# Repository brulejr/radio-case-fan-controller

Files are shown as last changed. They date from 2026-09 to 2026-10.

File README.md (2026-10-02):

# Radio Case Fan Controller

ESP32 + ESPHome temperature-controlled fan module for cooling enclosed radio
equipment cases (initial target: the ICOM IC-2730A compact organizer, reusable
for other go-box modules). Supports one Noctua 5V PWM fan (outbound only,
passive intake) or two (matched outbound + inbound), switchable in software.

## Status

**Working prototype, in production use.** Built on a protoboard carrier and
running in the radio case: temperature-driven fan control, dual-fan operation
and RPM monitoring are all verified on hardware.

The custom carrier PCB (rev A) is drawn and checked — see
[`hardware/pcb/`](hardware/pcb/) — and is ready to order.
The enclosure follows. Breadboard was development-lab only and is behind us.

## Hardware on hand

- ESP32-C6-WROOM-1 dev board (RISC-V, 2×15 headers, dual USB-C)
- HiLetgo DS18B20 waterproof temperature probe (1-Wire, stainless steel, ~380 mm cable)
- Noctua NF-A4x20 5V PWM fan(s)
- 12V → 5V buck converter with a **USB-C output** (any module ≥1A)

## Schematic

[`hardware/schematic.svg`](hardware/schematic.svg) — full electrical diagram.
[`docs/wiring.md`](docs/wiring.md) has the net-by-net connection table, the
connector pinouts, the BOM, and the order to bring the board up in.

Schematic

## Pinout (ESP32-C6-WROOM-1 dev board)

| Signal | GPIO | Side | Notes |
| --- | --- | --- | --- |
| DS18B20 data (1-Wire) | GPIO6  | Left | 4.7kΩ pull-up to 3.3V between data and VCC |
| Fan 1 (outbound) PWM  | GPIO20 | Right  | Hardware LEDC output, 25kHz per Noctua PWM spec  |
| Fan 1 tach | GPIO21 | Right  | Open-collector; 10kΩ pull-up to **3.3V**, not 5V |
| Fan 2 (inbound) PWM | GPIO18 | Right  | Hardware LEDC output, 25kHz |
| Fan 2 tach | GPIO19 | Right  | Open-collector; 10kΩ pull-up to **3.3V**, not 5V |

Pins chosen to avoid the C6 strapping pins (4, 5, 8, 9, 15 — 8 also drives the
onboard RGB LED, 9 is the BOOT button, 15 has no internal pull), the USB
Serial/JTAG pair (12, 13), and the UART0 pins wired to the USB bridge (16, 17).
GPIO14 is not broken out, and GPIO24–30 are consumed by the SPI flash bus.

The four fan signals sit as a contiguous block on the right header while the
1-Wire probe is on the left, putting it on the physically opposite side of the
board from the 25kHz PWM edges. Spare after this: GPIO0, 1, 2, 3, 7, 10, 11,
22, 23.

## Power wiring

- Radio supply (12V nominal, wide tolerance) → buck converter input, direct.
  No protection components by design — the box is fed from a battery or bench
  supply, which handle surge and reverse polarity at the source
- The buck's only output is **USB-C**, so 5V reaches the board through a USB-C
  cable into one of the dev board's two ports
- Both fans take 5V and GND from the dev board's header pins — so **fan power
  depends on the dev board**. See the power topology section of
  [`docs/wiring.md`](docs/wiring.md) for what that implies
- **One power source at a time**: the buck and both USB-C ports share a net.
  Don't leave the buck connected while a computer is plugged in
- No bulk or decoupling caps on the 5V rail; 4-pin PWM fans don't chop their
  supply current, and the dev board has its own input decoupling

## Fan PWM/tach notes

- Noctua 4-pin fans expect ~25kHz on the PWM control line; the ESP32-C6's
  hardware `LEDC` peripheral hits this natively at ~11-bit resolution (this is
  why an ESP32-class part over an ESP8266 — ESP8266's software PWM can't
  cleanly reach 25kHz and tends to produce audible whine)
- Tach line is open-collector: it only pulls low, never drives high, so a
  simple pull-up to 3.3V is safe — no level shifting needed
- Fans report 2 tach pulses per revolution; the ESPHome config's
  `pulse_counter` filter accounts for this
- **No PWM signal means full speed**, not stopped — the fan pulls its control
  input high internally. Expect a spin-up if you unplug a PWM line while the
  fan is powered
- Each fan draws 0.1A / 0.5W at full speed (Noctua spec)

## Software

`icom2370a-fan-controller.yaml` — ESPHome config. Key behavior:

- DS18B20 reading drives a linear PWM ramp between a configurable min/max
  temperature (exposed as tunable `number` entities, not hardcoded)
- "Dual Fan Mode" switch: on = both fans run the same curve; off = only
  Fan 1 (outbound) runs, Fan 2 output held at 0% for passive-intake mode
- Fallback WiFi AP + local API so the module stays controllable if the
  field WiFi network isn't up
- Local web UI at `http://<device-ip>/` for the sensors, fan-curve numbers and
  Dual Fan Mode switch, with its assets embedded in flash so it works with no
  internet. Needs `web_server_username` / `web_server_password` in `secrets.yaml`

### First flash

1. Copy `secrets.yaml.example` to `secrets.yaml` and fill in your values
2. Flash. The boot log lists the 1-Wire devices found on GPIO6; confirm the
   probe enumerates. No address needs configuring — see the note in the YAML
3. Confirm fan curve thresholds via Home Assistant or the ESPHome web UI
   before buttoning up the enclosure

## Repo layout

```
/esphome/icom2370a-fan-controller.yaml    # ESPHome config
/esphome/secrets.yaml.example
/hardware/schematic.svg                    # schematic / wiring diagram
/hardware/esp32-photo.jpg                  # dev board + protoboard carrier, for the header map
/hardware/pcb/                             # KiCad 8 carrier PCB, rev A
/docs/wiring.md                            # net list, connection table, BOM, bring-up order
README.md
.gitignore
```

Still to come under `/hardware/`: the OpenSCAD enclosure.

## Problem solving

Lessons from first bring-up on real hardware. [`docs/wiring.md`](docs/wiring.md)
carries the electrical detail.

### Start with the `[D][fan]` log line

It prints every 5s and shows the live setpoints alongside the computed duty:

```
[D][fan:197]: t=32.88 lo=25.0 hi=45.0 floor=0.30 -> duty=0.674 dual=1
```

The three setpoints are `restore_value: true`, so whatever you last set from the
web UI or Home Assistant **outranks `initial_value` in the YAML** and survives
both reboots and OTA updates. Trust this line, not the config file.

### Symptom table

| Symptom | Likely cause |
| --- | --- |
| Fan runs constantly, RPM flat `0.00`, no response to duty changes | PWM and tach swapped at the fan connector. Verify by **wire colour** — blue is PWM, green is tach — because pin numbering is exactly what's unreliable when this happens |
| Fan runs at full speed | No PWM signal reaching it. An open control line is held high by the fan's internal pull-up, which reads as 100% duty |
| Fan seems to idle quietly | It may in fact be at 100%. An NF-A4x20 is only ~18 dB(A) flat out, so full speed and idling sound alike without a reference |
| Fan turns at 0% duty | Something is wrong upstream — this fan **does** stop at 0%, verified on the bench |
| RPM reads `0.00` while the fan spins | Tach pull-up on the wrong rail, or the tach line open. A spinning fan's tach reads ~1.6V on a DC meter; a flat rail voltage means no pulses |
| Low hum on nearby 2 m / 70 cm radios while the fans run | Check both tach pull-up joints (R2/R3, 10 kΩ) first — a disconnected one was found during the investigation. RC filters, ferrites and the probe made no difference. Not yet fully resolved |
| RPM reads absurdly high (~234,000) | The `multiply` filter is wrong. `pulse_counter` reports pulses/min, so RPM = pulses/min ÷ 2 |

### Techniques worth remembering

**Raw versus published values.** `[D][pulse_counter]` prints the raw
`pulses/min`, untouched by filters. Comparing it against the published RPM
separates a sensor problem from a scaling problem.

**Measure at both ends of a wire.** Continuity from a GPIO to a header pin says
nothing about whether the fan's own conductor is landed there. Assuming it did
cost several rounds of diagnosis.

**Slow RPM feedback?** The pulse counters run at `update_interval: 60s`. Drop
them to `10s` temporarily while chasing a tach problem, then put them back.

**Changing setpoints without Home Assistant.** The device serves a local page at
`http://<device-ip>/` with the fan-curve numbers and the Dual Fan Mode switch.
Assets are embedded in flash, so it works with no internet.

**RF interference tests: no temperature means no PWM.** The control loop
returns early while the temperature is invalid, so with the probe unplugged, or
with `update_interval: never`, the PWM lines never switch and the fans get no
commanded duty. Any test that removes the probe therefore also changes the fans.
To separate them, leave the probe in and move **Fan Curve Min Temp** above or
below the case temperature — and **confirm from the `[D][fan]` duty and the RPM
readings which fans are actually running** before judging a result.

**Reference figures.** At ~67% duty expect roughly 4,050 RPM (Fan 1,
outbound) and 3,900 RPM (Fan 2, inbound) — useful for judging whether a reading
is plausible. (Recorded before the fan pin assignments were corrected, when the
entity names were swapped; the figures are attributed to the physical fans.)

## TODO

- [x] Design a custom PCB for the carrier board, using the protoboard build as
      the reference (rev A, [`hardware/pcb/`](hardware/pcb/))
- [x] Confirm the dev board header row spacing (25.4 mm)
- [ ] Order the rev A boards
- [ ] Design enclosure (OpenSCAD) once the PCB is finalized
- [ ] Consider stall detection (tach == 0 while PWM > 0) as a fault alert

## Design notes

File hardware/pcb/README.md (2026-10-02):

# Carrier PCB — rev A

KiCad 8 project for the custom carrier board that replaces the protoboard. The
ESP32-C6 dev board from the prototype plugs in unchanged. The buck converter
moves onto the board, so there's no USB-C cable between them. Every passive is
**through-hole**, for hand assembly.

Board, top view

| File | What |
| --- | --- |
| `fan-controller-carrier.kicad_sch` | schematic |
| `fan-controller-carrier.kicad_pcb` | layout, 2-layer, 1.6 mm |
| `carrier-top.svg` | preview render (copper + silk) |
| `fit-template.pdf` | 1:1 printable outline for space checking  |

Only stock KiCad 8 libraries are used. Nothing needs installing beyond KiCad.
ERC, DRC and schematic parity are all clean.

## Dev board header spacing

The socket rows J5/J6 are **25.4 mm (10 × 0.1") apart, centre to centre**,
confirmed against the dev boards on hand (2026-10-01). Boards of this type come
in 0.1" steps (22.86 / 25.4 / 27.94 mm), so a different dev board needs
checking before reuse. To change it, move J6 and re-route the filter block
between the rows.

## Board

- **90 × 54 mm**, sized for a **Hammond 1590B** die-cast box (inside 107 ×
  55.4 mm at the floor, 27 mm deep). The board sits between the lid-screw
  bosses with about 0.7 mm spare on each long side.
- 4 × M3 holes, 3.5 mm in from each corner. They are **not plated**, and there
  is a 3.6 mm copper keepout around each one. The screw heads and standoffs
  never touch GND, so board ground stays isolated from the enclosure.
- The bottom layer is almost entirely GND. It carries only the 5 V feed to the
  fans and two short tach links in the filter block.

### Height stack

| Item | mm, approx. |
| --- | --- |
| standoff | 5 |
| carrier PCB | 1.6 |
| female socket | 8.5 |
| dev board + USB-C / module | 5 |
| **top of dev board above enclosure floor** | **~20** |

U1, the electrolytics (~10–11 mm) and the fan plugs (~12 mm above the PCB) are
lower than that, which leaves about 7 mm under the 1590B's lid.

The filter block and R1 sit **under the dev board**, inside the 8.5 mm socket
gap. Lay the resistors flat and seat the disc capacitors low, with no more
than ~6 mm of body and leads above the board.

## Layout

```
 x=0 (left end panel)                                        x=90 (right end panel)
 ┌──────────────────────────────────────────────────────────────────┐
 │ H1                                                           H2  │
 │ J4 probe (XH, top) R6 C7 ─ top edge ─▶ GPIO6   ┌── dev board ──┐│
 │                                                │ J5 RST ... 5V ││ ANTENNA
 │ J1 12V  U1 R-78E      12V/USB warning   ◀USB  │  filter block ││ keepout
 │         C1 C2                                  │ J6 GND ... 5V ││
 │ J3 FAN2  J2 FAN1  C9 C8  5V FANS ONLY ◀─ lanes ─└───────────────┘│
 │ H3                                                           H4  │
 └──────────────────────────────────────────────────────────────────┘
```

- **Left end:** J1 (12 V) has its wire entry facing the left edge. J4 (probe)
  takes its plug from above. Both fan headers are in the bottom-left corner,
  also plugged from above, so the board can lie flat facing up.
- **Dev board:** the USB end points into the board and the antenna end
  overhangs the right edge, with a copper keepout under the antenna on both
  layers.
- **Filter block,** between the socket rows, in four rows starting nearest J6:

  | Row | Parts | Channel |
  | --- | ----- | ------- |
  | A | R4 + C3 | PWM1, GPIO20 |
  | B | R5 + C4 | PWM2, GPIO18 |
  | C | C5 + R2 | TACH1, GPIO21 |
  | D | C6 + R3 | TACH2, GPIO19 |

  Each filtered PWM line passes between two adjacent socket pins (0.3 mm track,
  0.27 mm clearance) to reach its lane. The tach parts connect on the bottom
  layer, so the tach and PWM lines never cross.
- **Fan lanes:** four non-crossing traces run to the headers, 1.5 mm apart:
  - GPIO18/19 → J3 (Fan 2, inbound, left header)
  - GPIO20/21 → J2 (Fan 1, outbound, right header)
- **1-Wire:** runs along the top edge, on the opposite side of the board from
  the fan lanes.

## Filtering

Rationale for each filter, from the prototype's RF interference investigation:

| Parts | Where | Why |
| ----- | ----- | --- |
| **C5/C6** 1 nF, with R2/R3 10 kΩ | tach lines, at the GPIO | The one prototype change that clearly reduced the hum was restoring a lost 10 kΩ tach pull-up. The likely mechanism is PWM edges coupling onto a weakly held tach line. The cap shunts that coupling; the 10 µs time constant is far shorter than the ≥ 6 ms between tach pulses. |
| **R4/C3, R5/C4** 220 Ω + 10 nF | PWM lines, at the GPIO | Insurance. It made no difference to the hum on the prototype, but it's proven harmless (fan control works through it) and it softens edges that run beside the tach wire in each fan cable. |
| **R6** 0 Ω, **C7** not fitted | 1-Wire, at J4 | Spare footprints: a ferrite and an RC on this line made no difference on the prototype. If C7 is ever fitted, keep it **≤ 470 pF**, or the 1-Wire bus stops working. |
| **C8/C9** 10 µF + 100 nF | fan 5 V, beside J2 | Standard decoupling, shared by both headers. |

The interference wasn't fully resolved on the prototype. See **RF interference**
below.

## Connectors

| Ref | Part | Mates with |
| --- | ---- | --- |
| J1 | 2-pos screw terminal, 5.08 mm (Phoenix MKDS 1,5/2-5,08) | 12 V leads, or a Powerpole pigtail |
| J2, J3 | 4-pin PC fan header, Molex 47053-1000 (DigiKey WM4330-ND) | the fan's own connector, via a 4-pin PWM extension such as the Noctua NA-EC1 (30 cm; chainable) |
| J4 | JST XH 3-pin, top entry (**B3B-XH-A**) — the plug goes straight down | XHP-3 housing + SXH crimps on the probe leads, or a pre-crimped XH pigtail soldered and heat-shrunk to them |

- **XH pitch is 2.50 mm,** not 2.54 mm, even though it's often sold as 2.54.
- **Meter the probe's wires before crimping.** Some batches use white for data.
- **The XH latch is friction only.** In the go-box, add a dab of RTV silicone
  or a cable tie.
- **Keep the fan extensions keyed and 4-wire.** A PWM/tach swap has bitten this
  build before, and some cheap extensions are 3-wire and drop PWM.

## Changes from the protoboard build

| | Protoboard | PCB rev A |
| -- | -- | -- |
| Buck | USB-C-output module, off-board, cable into dev board | **R-78E5.0-1.0** SIP-3 switching regulator on board (U1), with C1 10 µF / C2 22 µF |
| 5 V to dev board | USB-C cable | U1 drives the socket's two **5V pins** (= dev board VBUS) |
| Fan 5 V | from the dev board's 5V pins | straight from U1. Fans no longer depend on the dev board |
| Fans | screw terminals | keyed 4-pin headers + extension cables |
| Probe | screw terminal | JST XH |
| Filtering | none | see **Filtering** above |
| Everything else | — | same nets, GPIOs and pull-up values |

The "one power source at a time" rule still applies, and it is printed on the
silkscreen. With 12 V on the board, the dev board's USB VBUS is live. **Unplug
12 V before plugging in a USB cable.** Flash over OTA once the board is in the
box.

Input protection is still deliberately absent. See
[`docs/wiring.md`](../../docs/wiring.md).

## BOM

| Ref | Part | Footprint |
| --- | --- | --- |
| U1 | RECOM R-78E5.0-1.0 (or Murata OKI-78SR-5/1.5, same pinout) | SIP-3, 2.54 mm |
| C1 | 10 µF 25 V electrolytic | radial, 5 mm dia, 2.0 mm lead pitch |
| C2 | 22 µF 16 V electrolytic | radial, 5 mm dia, 2.0 mm lead pitch |
| C8 | 10 µF 16 V electrolytic | radial, 5 mm dia, 2.0 mm lead pitch |
| C3, C4 | 10 nF ceramic (code 103) | disc/MLCC, 2.5 mm lead pitch |
| C5, C6 | 1 nF ceramic (code 102) | disc/MLCC, 2.5 mm lead pitch |
| C9 | 100 nF ceramic (code 104) | disc/MLCC, 2.5 mm lead pitch |
| C7 | **not fitted** (≤ 470 pF if ever used) | disc/MLCC, 2.5 mm lead pitch |
| R1 | 4.7 kΩ, ¼ W | axial, 7.62 mm pitch |
| R2, R3 | 10 kΩ, ¼ W | axial, 7.62 mm pitch |
| R4, R5 | 220 Ω, ¼ W | axial, 7.62 mm pitch |
| R6 | 0 Ω jumper (or a wire link) | axial, 7.62 mm pitch |
| J1 | 2-pos screw terminal, 5.08 mm | THT |
| J2, J3 | 4-pin PC fan header, Molex 47053-1000 | THT |
| J4 | JST B3B-XH-A (top entry) | THT |
| J5, J6 | 1 × 15 female header, 2.54 mm, 8.5 mm tall | THT |
| H1–H4 | M3 standoffs, nylon or metal (holes are isolated) | — |

Electrolytic polarity: the square pad is **+**.

## RF interference — under investigation

The protoboard puts a low hum on nearby 2 m / 70 cm radios while Fan 1 is
running. A **disconnected 10 kΩ tach pull-up** on the outbound fan (GPIO21) was
found and resoldered, and the hum stopped on the bench, but it returned once
the unit was reassembled in place. The pull-up is at least a contributor; the
full cause is not yet confirmed.

Ruled out along the way:
- the buck converter
- the fan motors
- the probe and 1-Wire line (a ferrite and an RC filter on it made no difference)
- PWM edge speed (220 Ω + 10 nF on either PWM line made no difference)

Likely mechanism: with only the ESP32's ~45 kΩ internal pull-up, PWM edges couple
onto the tach line and nudge it through the logic threshold. The software pulse
counter takes an interrupt on every glitch. Its 13 µs filter discards them, so
RPM still reads plausibly while the CPU is being woken constantly.

This board's tach capacitors target that mechanism. Whatever the full answer,
**R2 and R3 are not optional.**

## Wi-Fi in an aluminum box

The dev board's PCB trace antenna is at the right-hand end of the board, and a
closed aluminum enclosure largely blocks it. Cooling does not need the network
(`reboot_timeout: 0s`), but the web UI, Home Assistant and OTA do. If you need
them, give the right end panel a plastic insert or a window in front of the
antenna.

## Fit template

`fit-template.pdf` is the board at 1:1 on an A4 landscape page. It shows the
outline, the part outlines, the dev board's footprint and crosshairs at the
M3 holes, with approximate part heights in a legend.

Print it at **100% / Actual size**, not "Fit to page". The page also fits US
Letter. Then check the 50 mm scale bar with a ruler before trusting the
outline.

## Fabrication outputs

These are not committed (`hardware/pcb/fab/` is git-ignored). Regenerate them
from this directory with:

```
mkdir -p fab/out
kicad-cli pcb export gerbers --layers F.Cu,B.Cu,F.SilkS,B.SilkS,F.Mask,B.Mask,Edge.Cuts \
    --subtract-soldermask -o fab/out/ fan-controller-carrier.kicad_pcb
kicad-cli pcb export drill --format excellon --excellon-units mm \
    --excellon-zeros-format decimal --excellon-separate-th \
    --generate-map --map-format gerberx2 -o fab/out/ fan-controller-carrier.kicad_pcb
cd fab/out && zip ../fan-controller-carrier-revA-gerbers.zip \
    *.gtl *.gbl *.gto *.gbo *.gts *.gbs *.gm1 *-PTH.drl *-NPTH.drl
```

Upload the zip as-is to JLCPCB, PCBWay or OSH Park. The drill maps
(`*-drl_map.gbr`) stay out of the zip; they're for people, and some fabs' file
detection trips over them.

Expected contents, useful for checking a fab's preview:

| | |
| --- | --- |
| Outline | 90.00 × 54.00 mm |
| Plated holes | 93: 17 vias 0.3 mm, 30 × 0.8, 3 × 0.95 (J4), 33 × 1.0, 8 × 1.02 (fan headers), 2 × 1.3 (J1) |
| Non-plated holes | 6: 4 × 3.2 mm (M3), 2 × 1.1 mm (fan-header pegs) |

Order settings: 2 layers, 1.6 mm, 1 oz copper, any soldermask colour, HASL
(lead-free) or ENIG. The narrowest trace and gap (0.3 / 0.27 mm) and the
smallest via (0.3 mm drill) are within every fab's standard limits.

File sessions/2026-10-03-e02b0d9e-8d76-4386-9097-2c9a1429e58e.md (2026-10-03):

# Persisting Claude conversations

- Session: `e02b0d9e-8d76-4386-9097-2c9a1429e58e`
- Started: 2026-10-03 07:55 EDT

---

## User

How do I persist these Claude AI conversations in the project? Can I do it automatically? Or, does it have to be some sort of manual copy-n-paste?

---

## Claude

Conversations are already saved automatically, just not inside your repo.

## Where they live now

Claude Code writes every session as a JSONL transcript here:

```
~/.claude/projects/-home-brulejr-ham-diy-radio-case-fan-controller/<session-id>.jsonl
```

- You can reopen one with `claude --continue` (most recent) or `claude --resume` (pick from a list). In VS Code, use the past-conversations list.
- By default, transcripts older than **30 days are deleted**. To keep them longer, set `"cleanupPeriodDays": 365` (or higher) in `~/.claude/settings.json`.

## Getting them into the project

**Manual, one session at a time:** run `/export`. It saves the current conversation as a readable text file or copies it to the clipboard. You can drop that file into something like `docs/sessions/`.

**Automatic:** add a hook. The `SessionEnd` and `PreCompact` hooks receive the session's `transcript_path` as input. A small script can copy that file, or convert it to Markdown, into the repo every time a session ends. This is the real "set it and forget it" option.

## What I'd actually recommend

Raw transcripts are noisy. They include every tool call and file dump, so they don't make good repo history. For this project, the useful parts of our conversations are the decisions. Examples are "power protection is upstream" and "the 1590B box is conditional". Those are better kept as:

- **A `CLAUDE.md` in the repo.** It's version-controlled, and I load it automatically at the start of every session. Right now those decisions live only in my memory folder under `~/.claude/projects/...`, which is outside git and specific to this machine.
- **Docs and commit messages** for design rationale, which you're already doing.

A good split: keep raw transcripts locally with a longer `cleanupPeriodDays`, and put the distilled decisions in `CLAUDE.md` or `docs/`.

Do you want me to set up a `SessionEnd` hook that saves transcripts to a gitignored `sessions/` folder, start a `CLAUDE.md` from the decisions already in memory, or both?

---

## User

Will the SessionEnd hook only write if I terminiate a session?

---

## Claude

Yes. `SessionEnd` fires only when a session actually ends:

- `/clear` (this ends the current session and starts a fresh one)
- Exiting normally, with `/exit`, Ctrl+D, or closing the conversation
- Logging out

It will **not** fire if the process dies abruptly, for example from a crash, `kill`, a closed terminal, or a reboot. It also won't fire for a session you leave open for days. In the VS Code extension, closing the panel should end the session, but I wouldn't count on that being reliable.

## The more robust option: a `Stop` hook

`Stop` fires every time I finish responding, so after every turn. Because the transcript file grows as the conversation goes, the hook can just overwrite the copy in the repo each time. Then the saved copy is never more than one turn out of date, however the session ends. The copy is fast and only rewrites one file, so the overhead is negligible.

A common setup:

- **`Stop`**: copy or overwrite `sessions/<session-id>.jsonl` (or a Markdown conversion of it) after every turn.
- **`SessionEnd`** (optional): do any final step, like converting to Markdown or tidying up.

Do you want me to set up the `Stop`-hook version? If so, should it save raw JSONL, which is complete but noisy, or convert to readable Markdown with just your messages and my replies?

---

## User

I like the idea of both; however, I don't think we should put the `sessions` folder in `.gitignore`. Let if write out to the project, or do you see a problem with that?

---

## Claude

Committing the sessions is fine in principle. I checked the repo and old transcripts, and there are three real problems with committing the **raw JSONL**:

1. **Size.** Two of your earlier transcripts are **18 MB and 11 MB**. They contain every file I read, including KiCad files, plus every tool output. Git keeps every version forever, and with a `Stop` hook rewriting the file after every turn, the repo would grow quickly.
2. **Secrets.** Four of the existing transcripts mention `wifi_password`, `api_key`, or `ota_password`. These may only be `!secret` references in the ESPHome YAML. But if I ever ran `cat secrets.yaml` or a log printed a key, the actual value is in the transcript. You gitignore `secrets.yaml` for a reason, and a committed transcript would get around that. Your remote is on GitHub, so if the repo is public, those transcripts would be public too.
3. **Always-dirty working tree.** The `Stop` hook changes a file after every turn, so `git status` is never clean mid-session. Any `git add -A` or `git commit -a` would sweep in a half-finished transcript.

## Recommendation: commit Markdown, not JSONL

- Have the hooks write **`sessions/<date>-<session-id>.md`** containing only your messages and my text replies. Tool calls and file dumps are left out, so it's small and readable, and diffs are meaningful.
- Don't copy the raw JSONL into the repo at all. It already lives in `~/.claude/projects/...`, and with a higher `cleanupPeriodDays` it'll stick around.
- Have the converter **redact** anything that looks like a secret value, as a safety net.
- Commit the session file yourself when it makes sense, for example alongside the work it produced, rather than having the hook commit it automatically.

Even after this filtering, my replies can still quote things back. If the repo is public, skim a session file before committing it.

Should I build it that way? That means a small converter script in the repo plus `Stop` and `SessionEnd` hooks in `.claude/settings.json`.

---

## User

Can we use the STOP mechanism in conjunction with `sessions/<date>-<session-id>.md` files and not commit the JSONL files?

---

## Claude

The transcript format is clean: the user text blocks are just your messages, and the session has an auto-generated title. Now I'll write the converter and the hook config.

Now I'll test it on this session and on the 18 MB transcript, and check the redaction.

The 18 MB transcript came out as a 212 KB Markdown file. I'll check what the two redactions in it caught.

I set this up, and tested it by running the script by hand on this conversation and on your largest old one. It hasn't yet fired as a real hook.

**What happens now:** after every reply I give, and again when a session ends, a script rewrites `sessions/<date>-<session-id>.md` for that conversation. The file keeps only your messages and my text replies, so tool calls, file dumps, my thinking and IDE context are left out. The raw JSONL is never copied into the repo; it stays only in `~/.claude/projects/...`.

**Test results:**
- This conversation came out as [sessions/2026-10-03-e02b0d9e-8d76-4386-9097-2c9a1429e58e.md](sessions/2026-10-03-e02b0d9e-8d76-4386-9097-2c9a1429e58e.md), with its auto-generated title as the heading.
- The 18 MB transcript from Sep 21 shrank to a 212 KB Markdown file.
- In that Sep 21 session, the redaction caught a **real `web_server_password` value**, written out in a YAML snippet. That's exactly the kind of leak I was worried about. If that's your actual device password, it's in the old raw transcript locally, but it won't go into git.
- Redaction also had one harmless false positive, where it blanked a word in an OAuth error message. It's deliberately cautious.

**What I added:**
- [.claude/hooks/export-session.py](.claude/hooks/export-session.py): the converter and redaction. If it ever errors, it fails quietly so it can't interrupt a session.
- [.claude/settings.json](.claude/settings.json): the `Stop` and `SessionEnd` hooks. Both files are meant to be committed.

**Things to know:**
- Claude Code may not pick up the new hooks until you restart it or approve them under `/hooks`.
- Because the file is rewritten after every reply, `git status` will show `sessions/` as changed mid-session. Commit it when it makes sense, and skim a file first if the repo is public.
- Nothing is committed yet. The Sep 21 export is a leftover from my test. Keep it as a start on backfilling old sessions, or delete it.

Two options from here: I can backfill the other four old sessions the same way, and I can raise `cleanupPeriodDays` in your user settings so the raw transcripts don't get deleted after 30 days.

---

## User

This looks good. Let's commit and push it on the current branch.

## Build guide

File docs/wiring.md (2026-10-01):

# Wiring

Companion to [`hardware/schematic.svg`](../hardware/schematic.svg). The schematic
is the picture; this page is the thing you build from and check against.

Schematic

Target hardware is a **carrier board** — prototype board first, then a custom
PCB. Breadboarding is development-lab only.

This page describes the protoboard build. The custom PCB keeps every net and
GPIO but moves the buck on-board and feeds 5 V through the socket instead of a
USB-C cable — see [`hardware/pcb/README.md`](../hardware/pcb/README.md).

## Power topology

This is the least obvious part of the design, so it comes first.

The buck converter's **only output is a USB-C socket**. There are no terminals
or pads on it. So 5 V reaches the carrier board through the dev board:

```
J1 12V ──────────────▶ U1 buck ─[USB-C cable]─▶ dev board USB-C
                                                      │
                                       dev board 5V pin (= VBUS)
                                                      │
                                    ┌─────────────────┴─────────────────┐
                                 Fan 1 pin 2                       Fan 2 pin 2
```

The dev board's two `5V` header pins and both USB-C VBUS lines are one net.
Fans tap that net at the header pins.

Two consequences worth understanding before you build:

**Fan power depends on the MCU board.** Pull or kill the dev board and the fans
lose power. This is a deliberate accepted trade for wiring simplicity, but note
the interaction: with no PWM signal a Noctua 4-pin fan runs at **full speed**
(the input is pulled up internally, per the Intel 4-wire spec). So a hung MCU
that still has power gives you full-blast cooling — the safe failure — whereas a
dead MCU board gives you no cooling at all.

**One power source at a time.** The buck and either USB-C port feed the same
net. Do not have the buck connected while a computer is plugged into the other
USB port. With OTA configured you rarely need USB after the first flash, so
this is mostly a bench-discipline rule.

## Nets

| Net | Carries | Members |
| --- | --- | --- |
| `+12V_IN`  | radio supply, unregulated  | J1 `+` → U1 `IN+` |
| `+5V` | 5.00 V, via USB-C | U1 USB-C → dev board VBUS → dev board `5V` pins → Fan 1 pin 2, Fan 2 pin 2 |
| `+3V3` | dev board onboard regulator| dev board `3V3` → DS18B20 red, R1, R2, R3 |
| `GND` | common return | J1 `−`, U1 `IN−`, dev board `GND`, DS18B20 black, Fan 1 pin 1, Fan 2 pin 1 |
| `1W_DATA`  | DS18B20 1-Wire bus | `GPIO6` ↔ DS18B20 yellow, R1 to `+3V3` |
| `TACH1/2`  | fan speed, open-collector  | `GPIO21` ↔ Fan 1 pin 3 (R2 to `+3V3`); `GPIO19` ↔ Fan 2 pin 3 (R3) |
| `PWM1/2` | 25 kHz fan control | `GPIO20` → Fan 1 pin 4; `GPIO18` → Fan 2 pin 4 |

`GND` is one net throughout. On the schematic the input-side and output-side
segments are drawn without a wire between them — the path runs through U1 and
the USB-C cable, and drawing it would mean crossing every signal line on the
board. They are the same net.

## Connection table

Build from this. Each row is one wire.

### Power in (12 V side)

| From | To | Notes |
| --- | --- | --- |
| J1 `+` | U1 `IN+` | 12 V nominal from the radio supply |
| J1 `−` | U1 `IN−` | `GND` |

Two wires, no components. **This is deliberate**: the box is fed from a battery
or a bench supply, and surge and reverse-polarity handling live at the source —
a bench supply current-limits, and a battery feed through polarised Powerpoles
cannot be reversed at the connector.

Don't add protection components here. The one thing to note is that the
assumption travels with the supply: if this module is ever fed from something
unprotected, it needs revisiting.

### 5 V side

| From | To | Notes |
| --- | --- | --- |
| U1 USB-C | dev board USB-C | USB-C cable. Either port works; the CH343 port leaves the native port free for JTAG |
| dev board `5V` pin  | Fan 1 pin 2 | yellow on the Noctua connector |
| dev board `5V` pin  | Fan 2 pin 2 | omit if running single-fan |
| dev board `GND` pin | Fan 1 pin 1 | black |
| dev board `GND` pin | Fan 2 pin 1 | |

No bulk or decoupling capacitors on this rail. The dev board has its own input
decoupling, and 4-pin PWM fans don't chop their supply current — the PWM line
drives the fan's internal commutation, so there's little for a bulk cap to do.

### Signals

| MCU pin  | Side  | To | Passive | Notes |
| --- | ----- | --- | --- | --- |
| `GPIO6`  | Left  | DS18B20 yellow | R1 4.7 kΩ to `+3V3` | 1-Wire data |
| `GPIO18` | Right | Fan 2 pin 4 (blue)  | — | LEDC PWM, 25 kHz |
| `GPIO19` | Right | Fan 2 pin 3 (green) | R3 10 kΩ to `+3V3`  | tach, open-collector  |
| `GPIO20` | Right | Fan 1 pin 4 (blue)  | — | LEDC PWM, 25 kHz |
| `GPIO21` | Right | Fan 1 pin 3 (green) | R2 10 kΩ to `+3V3`  | tach, open-collector  |
| `3V3` | Left  | DS18B20 red | — | also feeds R1/R2/R3 |
| `GND` | Either| DS18B20 black | — | |

> **R1, R2 and R3 all go to `+3V3`, never to `+5V`.** The fan's tach transistor
> only pulls low — the pull-up alone sets the high level, so a pull-up on the
> 5 V rail puts 5 V onto a 3.3 V GPIO whose absolute maximum is 3.6 V. The fan
> still appears to work and the only symptom is a tach that reads a flat
> `0.00 RPM`, so this fails silently. Check the resistor's upper end lands on
> the dev board's `3V3` pin before first power-up.

R1, R2 and R3 all live on the carrier board next to the dev board, not out at
the sensor or fan. At these cable lengths the pull-up position makes no
measurable difference, and keeping them on the board means the probe and fans
are plain pluggable assemblies with no components buried in a cable run.

## Carrier board connectors

Pick pitches that are integer multiples of **2.54 mm**. A 3.5 mm terminal block
will not fit 0.1" protoboard, and you lose the property that the protoboard
footprint and the PCB footprint are identical.

| For | Use | Why |
| --- | --- | --- |
| Fans (×2) | 4-pin PC fan header, 2.54 mm, THT (Molex 47053-1000 or equivalent) | The fan already has the mating half — keyed, no crimping |
| DS18B20 | 3-position screw or push-in terminal, 2.54 or 5.08 mm | Each conductor lands individually, so the varying lead colours can't cause a reversal |
| 12 V in | 2-position screw terminal, 5.08 mm, or a Powerpole pigtail | 5.08 mm is exactly 2× the grid |
| Dev board | 2× 15-pin female headers | Socket it — keeps the MCU field-replaceable |

> **Silkscreen the fan headers `5V FANS ONLY`.** They are physically identical
> to 12 V motherboard fan headers. A 12 V fan in your board merely runs slow,
> but your 5 V fan in a real 12 V header is destroyed instantly. Label the fan
> pigtails too — the fan is the part that wanders off.

A 3-pin fan connector also mates with a 4-pin header (PWM simply unconnected),
if you ever want to fall back to voltage-controlled fans.

## Connector pinouts

**Noctua 4-pin** (looking into the fan's connector, tab down):

| Pin | Colour | Function | Goes to |
| --- | --- | --- | --- |
| 1 | black  | GND | `GND` |
| 2 | yellow | +5 V | dev board `5V` pin |
| 3 | green  | tach | Fan 1 GPIO21 / Fan 2 GPIO19, pulled to +3.3 V |
| 4 | blue | PWM in | Fan 1 GPIO20 / Fan 2 GPIO18 |

**DS18B20 waterproof probe**: red = VDD, yellow = data, black = GND. Some
batches ship red/white/black — white is then the data line. Meter it before you
trust the colours.

## The dev board

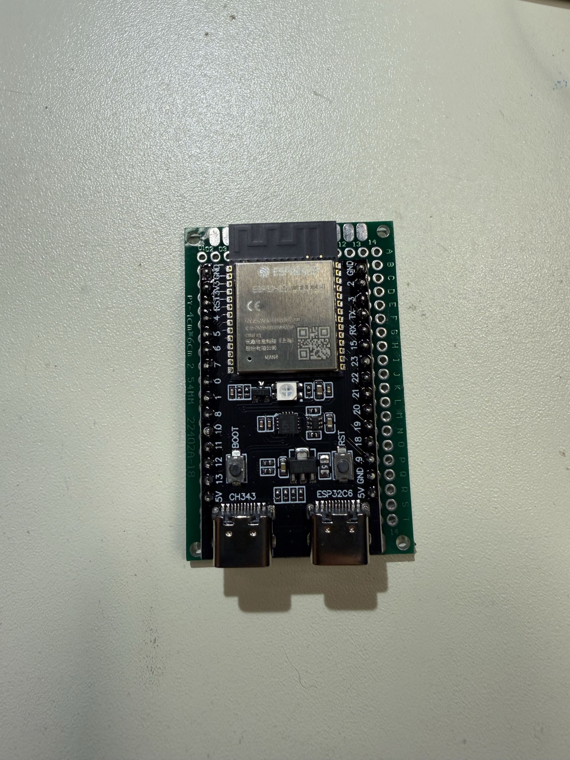
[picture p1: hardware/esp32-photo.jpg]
ESP32-C6 dev board on the protoboard carrier


A third-party ESP32-C6-WROOM-1 board, **2×15 headers**, with two USB-C ports
(one behind a CH343 USB-UART bridge, one native ESP32-C6 USB/JTAG), BOOT and
RST buttons, and an addressable RGB LED on GPIO8.

Header map, top to bottom with the USB connectors at the bottom:

| Left (15) | Right (15) |
| --- | --- |
| RST, 3V3, GND, 4, 5, **6**, 7, 0, 1, 8, 10, 11, 12, 13, 5V | GND, 2, 3, TX, RX, 15, 23, 22, **21, 20, 19, 18**, 9, GND, 5V |

This board brings out **all 23 usable GPIOs** on the module (0–13, 15, 18–23,
plus TX/RX = GPIO16/17), so nothing is omitted.

The split across sides is deliberate: the four fan signals sit together on the
right, and the 1-Wire probe is on the left — the 25 kHz PWM edges are the
noisiest thing on the board and the 1-Wire bus, pulled up through 4.7 kΩ over
~380 mm of cable, is the most susceptible.

The schematic groups pins by function rather than physical position, so its pin
order does not match the header — go by pin name.

**Do not use** GPIO4, 5, 8, 9 or 15 (strapping; 8 drives the RGB LED, 9 is the
BOOT button, 15 has no internal pull resistor), GPIO12/13 (native USB) or
GPIO16/17 (UART0 to the CH343). GPIO14 is not broken out and GPIO24–30 are the
SPI flash bus.

## Carrier board layout

The right-hand column reads, bottom-up: `5V, GND, 9, 18, 19, 20, 21`. Every
signal both fan headers need — PWM, tach, +5 V and ground — is one contiguous
run at the **bottom-right corner**. Put both fan headers there and all the fan
wiring stays in one compact zone with no runs under the board.

GPIO6 for the probe is on the left side, well away from it, so the noise
separation falls out of the physical layout rather than needing thought.

Two practical notes:

- A 4×6 cm protoboard is tight once the dev board is placed. The buck converter
  is a module in its own right and will likely need to live off-board, with only
  the USB-C cable arriving at the carrier.
- Socket the dev board on female headers rather than soldering it through.

## Grounding

Star-ground at the dev board's `GND` pins — that is where `GND` reaches the
carrier board, since the buck's return arrives through the USB-C cable.
Run separate returns from there to each fan rather than daisy-chaining one fan's
return through the other.

## Bring-up order

1. With nothing plugged into it, power U1 and confirm its USB-C output reads
   **5.00 V** on a meter. Do this first, every time — an adjustable module can
   ship set anywhere in its range, and feeding the dev board's USB-C port from a
   mis-set buck ends the session.
2. Power down. Connect the USB-C cable to the dev board only. Power up, confirm
   the board enumerates and the `3V3` pin reads ~3.3 V.
3. Add the DS18B20 and R1. Flash, and confirm the probe enumerates in the boot
   log. The config deliberately pins no address — the sole device on the bus is
   selected automatically, so the firmware is portable across builds.
   **Unplug the buck while flashing over USB** — one source at a time.
4. Add Fan 1 and R2. Confirm PWM response and a plausible RPM reading.
5. Add Fan 2 and R3 if running dual-fan.

## Bill of materials — electrical

| Ref | Part | Qty | Notes |
| --- | --- | --- | --- |
| U1 | 12 V → 5 V buck converter, USB-C out  | 1 | any module ≥1 A; no specific part required |
| U2 | ESP32-C6-WROOM-1 dev board, 2×15 | 1 | socket it, don't solder down |
| — | DS18B20 waterproof probe, ~380 mm | 1 | HiLetgo |
| Fan 1/2 | Noctua NF-A4x20 5V PWM | 1–2 | 0.1 A / 0.5 W each; Fan 2 optional |
| J2, J3 | 4-pin fan header, 2.54 mm THT | 2 | Molex 47053-1000 or equivalent |
| J4 | 3-pos terminal block, 2.54 / 5.08 mm  | 1 | DS18B20 probe |
| J1 | 2-pos screw terminal / Powerpole | 1 | 12 V supply entry |
| — | 2× 15-pin female header | 1 set | dev board socket |
| R1 | 4.7 kΩ resistor | 1 | 1-Wire pull-up |
| R2, R3 | 10 kΩ resistor | 1–2 | tach pull-ups, one per fan |

Current budget: each fan is **0.1 A / 0.5 W** (Noctua spec). The C6 module draws
on the order of 100 mA average with Wi-Fi up and a few hundred mA on transmit
peaks. Call it 0.55 A worst case — trivial for a USB-C connection, and well
inside any 2 A buck.

## Gotchas

- **Never pull a tach line up to +5 V.** The fan's tach transistor only pulls
  low; the pull-up sets the high level, and a 5 V pull-up puts 5 V straight onto
  a GPIO. R2/R3 go to `+3V3`.
- **Never plug a 5 V Noctua into a 12 V fan header.** It is destroyed instantly.
  The connector gives you no protection — it's the same part either way.
- **No PWM signal means full speed**, not stopped. If you probe or disconnect
  a PWM line with the fan powered, expect it to spin up.
- **The three fan-curve setpoints persist in flash and outrank the YAML.** They
  are `restore_value: true`, so `initial_value` applies only to a device that has
  never had one set. Once you change Min Temp, Max Temp or Minimum Duty from the
  web UI or Home Assistant, that value survives reboots *and* OTA updates — the
  config file stops being the source of truth for them. If the curve behaves
  unexpectedly, read the live values off the `[D][fan]` log line rather than
  trusting the YAML.
- `reboot_timeout` in the `wifi:` block is set to `0s`. The ESPHome default is
  15 min, which reboots the device when WiFi is absent — undesirable here, since
  cooling stops while the board reboots. Cooling should not depend on the
  network.
- The ESPHome config also sets `INPUT_PULLUP` on the tach pins. That's belt and
  braces — the internal pull-up is ~45 kΩ, weak enough that a long fan lead can
  round the edge off. Keep the external 10 kΩ parts. **A missing one also causes
  RF interference:** with only the internal pull-up, PWM edges couple onto the
  tach line, and the resulting interrupt storm put a hum on nearby radios. The
  RPM still reads plausibly, so check the joints rather than trusting the
  reading.
- PWM is driven push-pull at 3.3 V from the C6's LEDC peripheral. Noctua's 5 V
  PWM fans accept a 3.3 V control signal, so no level shifter is needed.
- Fan behaviour below ~20 % duty is not specified by the 4-wire standard. The
  config's `min_duty` default of 30 % exists for this reason. **The NF-A4x20 5V
  PWM does stop at 0 % duty** — verified on the bench, so single-fan mode really
  does leave Fan 2 stationary rather than idling.
- **If a fan runs constantly and its RPM reads a flat `0.00`, suspect PWM and
  tach swapped.** With the PWM line open the fan's internal pull-up holds it at
  100 %, and the pulse counter sits on a static line with no edges — so the fan
  appears to run at a "low level" (a 40 mm Noctua is only ~18 dB(A) flat out)
  and never responds to duty changes. Verify by **wire colour, not pin number**:
  blue is PWM, green is tach. Pin numbering is exactly what's in doubt when this
  happens.

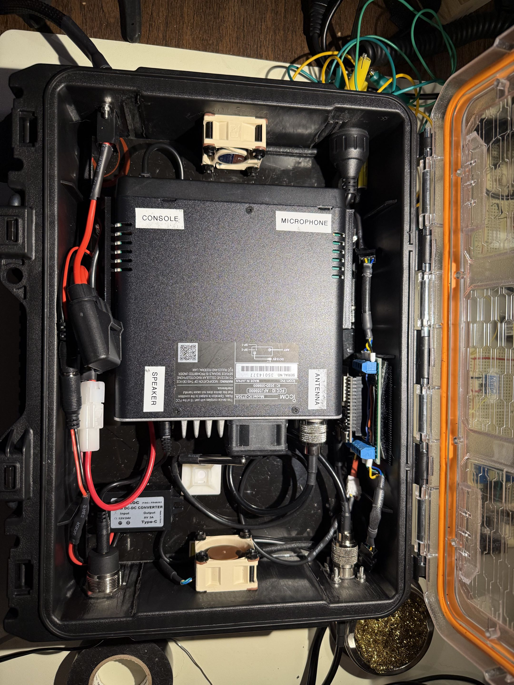
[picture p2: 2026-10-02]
esphome/radio-case-installation-01.jpg

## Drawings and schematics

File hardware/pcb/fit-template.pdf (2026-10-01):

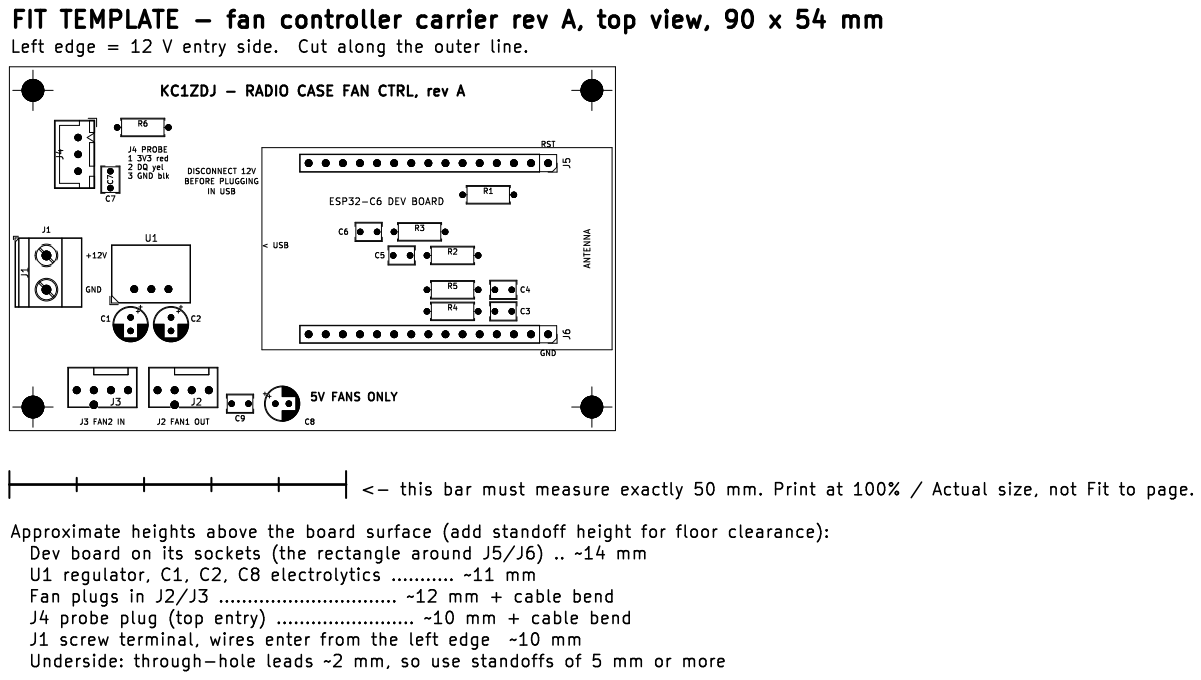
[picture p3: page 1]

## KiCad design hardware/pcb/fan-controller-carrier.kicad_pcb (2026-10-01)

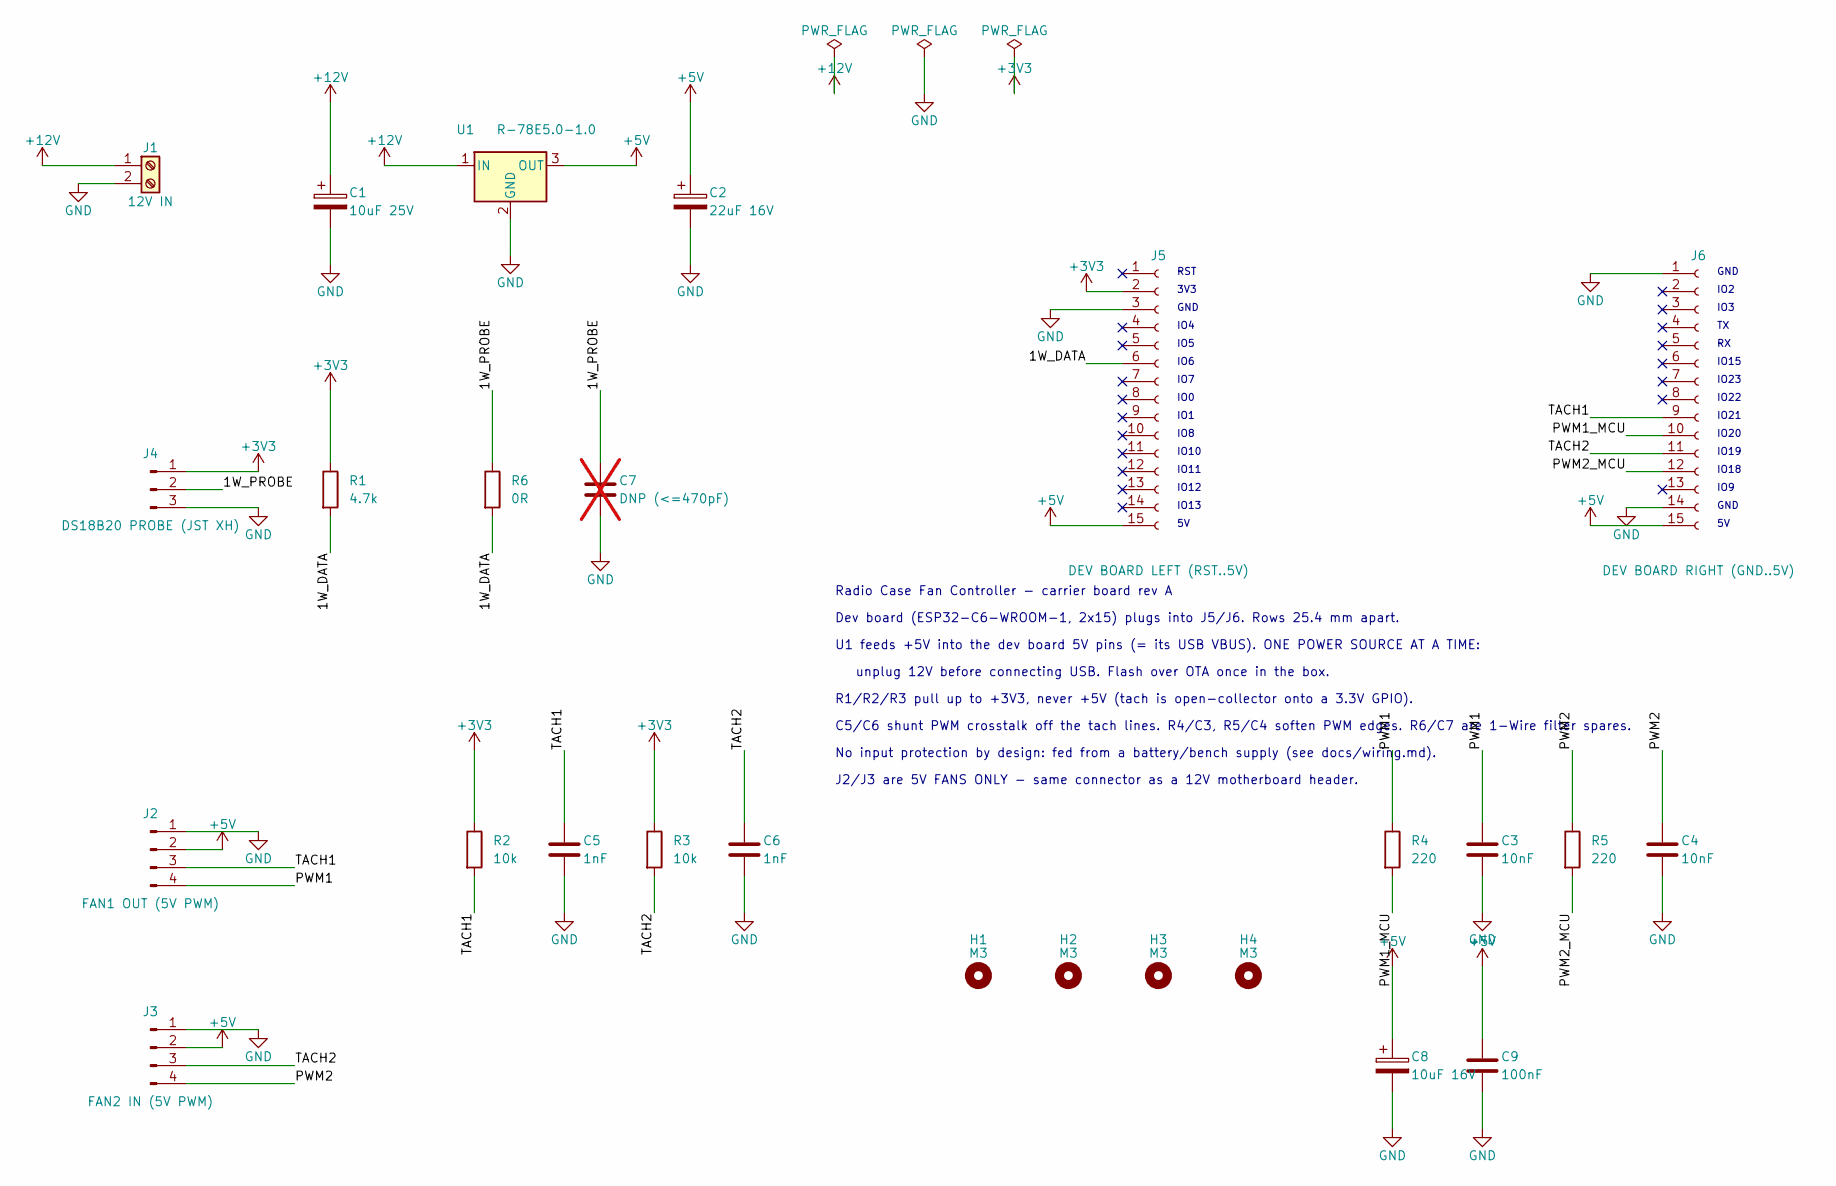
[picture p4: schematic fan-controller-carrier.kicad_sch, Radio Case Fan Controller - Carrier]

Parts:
C1: 10uF 25V; CP_Radial_D5.0mm_P2.00mm
C2: 22uF 16V; CP_Radial_D5.0mm_P2.00mm
C3, C4: 10nF; C_Disc_D3.8mm_W2.6mm_P2.50mm
C5, C6: 1nF; C_Disc_D3.8mm_W2.6mm_P2.50mm
C7: DNP (<=470pF); C_Disc_D3.8mm_W2.6mm_P2.50mm; not fitted
C8: 10uF 16V; CP_Radial_D5.0mm_P2.00mm
C9: 100nF; C_Disc_D3.8mm_W2.6mm_P2.50mm
H1, H2, H3, H4: M3; MountingHole_3.2mm_M3
J1: 12V IN; TerminalBlock_Phoenix_MKDS-1,5-2-5.08_1x02_P5.08mm_Horizont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
J2: FAN1 OUT (5V PWM); FanPinHeader_1x04_P2.54mm_Vertical
J3: FAN2 IN (5V PWM); FanPinHeader_1x04_P2.54mm_Vertical
J4: DS18B20 PROBE (JST XH); JST_XH_B3B-XH-A_1x03_P2.50mm_Vertical
J5: DEV BOARD LEFT (RST..5V); PinSocket_1x15_P2.54mm_Vertical
J6: DEV BOARD RIGHT (GND..5V); PinSocket_1x15_P2.54mm_Vertical
R1: 4.7k; R_Axial_DIN0207_L6.3mm_D2.5mm_P7.62mm_Horizontal
R2, R3: 10k; R_Axial_DIN0207_L6.3mm_D2.5mm_P7.62mm_Horizontal
R4, R5: 220; R_Axial_DIN0207_L6.3mm_D2.5mm_P7.62mm_Horizontal
R6: 0R; R_Axial_DIN0207_L6.3mm_D2.5mm_P7.62mm_Horizontal
U1: R-78E5.0-1.0; Converter_DCDC_RECOM_R-78E-0.5_THT

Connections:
+3V3: J4.1, J5.2, R1.1, R2.1, R3.1
+5V: C2.1, C8.1, C9.1, J2.2, J3.2, J5.15, J6.15, U1.3 (OUT)
+12V: C1.1, J1.1, U1.1 (IN)
/1W_DATA: J5.6, R1.2, R6.2
/1W_PROBE: C7.1, J4.2, R6.1
/PWM1: C3.1, J2.4, R4.1
/PWM1_MCU: J6.10, R4.2
/PWM2: C4.1, J3.4, R5.1
/PWM2_MCU: J6.12, R5.2
/TACH1: C5.1, J2.3, J6.9, R2.2
/TACH2: C6.1, J3.3, J6.11, R3.2
GND: C1.2, C2.2, C3.2, C4.2, C5.2, C6.2, C7.2, C8.2, C9.2, J1.2, J2.1, J3.1, J4.3, J5.3, J6.1, J6.14, U1.2 (GND)

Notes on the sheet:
RST
IO8
IO10
IO11
IO12
IO13
3V3
GND
IO4
IO5
IO6
IO7
IO0
IO1
IO20
IO19
IO18
IO9
IO2
IO3
IO15
IO23
IO22
IO21
Radio Case Fan Controller - carrier board rev A
Dev board (ESP32-C6-WROOM-1, 2x15) plugs into J5/J6. Rows 25.4 mm apart.
U1 feeds +5V into the dev board 5V pins (= its USB VBUS). ONE POWER SOURCE AT A TIME:
unplug 12V before connecting USB. Flash over OTA once in the box.
R1/R2/R3 pull up to +3V3, never +5V (tach is open-collector onto a 3.3V GPIO).
C5/C6 shunt PWM crosstalk off the tach lines. R4/C3, R5/C4 soften PWM edges. R6/C7 are 1-Wire filter spares.
No input protection by design: fed from a battery/bench supply (see docs/wiring.md).
J2/J3 are 5V FANS ONLY - same connector as a 12V motherboard header.

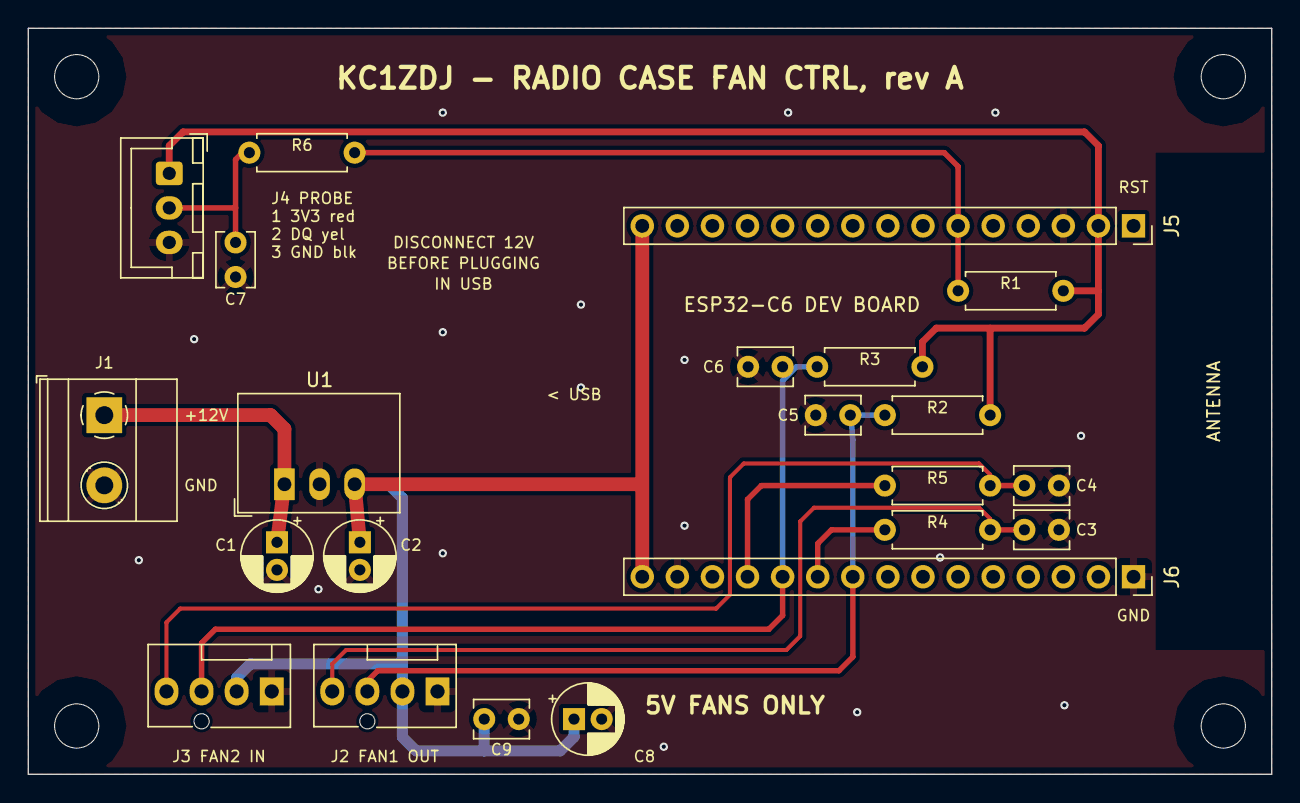
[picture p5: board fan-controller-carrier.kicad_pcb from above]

Board: 2 copper layers, 90.0 x 54.0 mm, 26 parts (0 on the bottom side), 12 nets.

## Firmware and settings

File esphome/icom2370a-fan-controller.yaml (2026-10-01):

esphome:
  name: icom2370a-fan-controller
  friendly_name: IC-2730A Case Fan Controller

  # Stamps a firmware version into the build. Exposed via the logger, mDNS and
  # the API's device_info, so Home Assistant shows which build is on the board.
  # Bump this whenever you flash a meaningful change.
  project:
    name: "brulejr.radio-case-fan-controller"
    version: "0.1.0"

esp32:
  variant: esp32c6
  framework:
    # ESP32-C6 is not supported by the Arduino framework in ESPHome
    type: esp-idf

logger:

api:
  encryption:
    key: !secret api_encryption_key

ota:
  - platform: esphome
    password: !secret ota_password

wifi:
  ssid: !secret wifi_ssid
  password: !secret wifi_password

  # Default is 15min: ESPHome reboots when WiFi can't be reached. Cooling stops
  # while the board reboots, and the fans are powered through it — so cooling
  # must not depend on the network being present.
  reboot_timeout: 0s

  # Fallback hotspot if WiFi is unavailable (e.g. field deployment, no AP)
  ap:
    ssid: "Icom-2730A-Fan-Fallback"
    password: !secret fallback_password

captive_portal:

# Local control page at http://<device-ip>/ — sensors, the fan-curve numbers and
# the Dual Fan Mode switch, without needing Home Assistant.
#
# local: true embeds the CSS/JS in flash. By default they're fetched from
# oi.esphome.io, which would leave the page broken in a field deployment with no
# internet — exactly the case this box is built for.
web_server:
  port: 80
  version: 2
  local: true
  auth:
    username: !secret web_server_username
    password: !secret web_server_password

# --- Temperature probe (DS18B20 on 1-Wire) ---
one_wire:
  - platform: gpio
    # J1 header, deliberately on the opposite side of the board from the fan
    # PWM lines (GPIO18/20 on J3) to keep 25kHz switching noise off the bus
    pin: GPIO6
    # NOTE: use a 4.7k pull-up resistor between the DS18B20 data line and 3.3V

sensor:
  - platform: dallas_temp
    # No `address:` on purpose. With a single device on the bus ESPHome selects
    # it automatically and logs the address it found, so the same firmware runs
    # on any build of this module without editing. Pin an address only if a
    # second 1-Wire device is ever added.
    name: "Enclosure Temperature"
    id: case_temp
    update_interval: 5s
    filters:
      - median:
          window_size: 5
          send_every: 5

  # Noctua fans output 2 tach pulses per revolution.
  #
  # use_pcnt: false was added while chasing a flat 0.00 pulses/min, which turned
  # out to be PWM and tach swapped at the fan connectors — the tach line never
  # carried a signal, so the hardware PCNT path was never actually proven
  # faulty. Kept because software edge counting is more than adequate here: the
  # tach tops out near 167 Hz (~5000 RPM x 2 pulses / 60). Drop it if you want
  # to retest the hardware counter.
  - platform: pulse_counter
    pin:
      number: GPIO21
      mode: INPUT_PULLUP
    use_pcnt: false
    # Drop to 10s as a temporary debugging aid should a tach problem arise —
    # see the Problem solving section of the README.
    update_interval: 60s
    name: "Fan 1 (Outbound) RPM"
    id: fan1_rpm
    unit_of_measurement: "RPM"
    filters:
      # pulse_counter reports pulses/min, and the fan gives 2 pulses per
      # revolution, so RPM = pulses/min / 2.
      - multiply: 0.5

  - platform: pulse_counter
    pin:
      number: GPIO19
      mode: INPUT_PULLUP
    use_pcnt: false
    # Drop to 10s as a temporary debugging aid should a tach problem arise —
    # see the Problem solving section of the README.
    update_interval: 60s
    name: "Fan 2 (Inbound) RPM"
    id: fan2_rpm
    unit_of_measurement: "RPM"
    filters:
      - multiply: 0.5 # pulses/min / 2 pulses-per-rev

# --- PWM control lines to fans (hardware LEDC @ 25kHz, per Noctua spec) ---
output:
  - platform: ledc
    pin: GPIO20
    id: fan1_pwm_out
    frequency: 25000 Hz

  - platform: ledc
    pin: GPIO18
    id: fan2_pwm_out
    frequency: 25000 Hz

# --- Mode toggle: dual-fan (in+out) vs single-fan (outbound only, passive intake) ---
switch:
  - platform: template
    name: "Dual Fan Mode"
    id: dual_fan_mode
    optimistic: true
    restore_mode: RESTORE_DEFAULT_ON
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

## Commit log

2026-09-21 Adds wiring schematic
2026-09-21 Updates wiring schematic for visibility on Github
2026-09-23 Migrate from ESP32 to ESP32-C6
    The ESP32-C6 uses a different GPIO range (0-30, with 24-30 consumed by the
    SPI flash bus), so GPIO25/26/27/32 do not exist on this part. The C6 is also
    unsupported by the Arduino framework in ESPHome and requires ESP-IDF.
    Platform:
    - esp32: board esp32dev + arduino -> variant esp32c6 + esp-idf
    - isnan -> std::isnan, for ESP-IDF's C++ <cmath>
    - Document the pulse_counter `use_pcnt: false` software fallback; the tach
    tops out near 167 Hz (~5000 RPM x 2 pulses / 60), well within its range
    Pin remap, avoiding the C6 strapping pins (4, 5, 8, 9, 15), the USB
    Serial/JTAG pair (12, 13) and the UART0 pins wired to the USB bridge (16, 17):
    1-Wire GPIO4 -> GPI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
    [icom-2730a-fan-controller.yaml]
2026-09-24 Update for actual dev board, USB-C power topology, and no protection stage
    Three related changes that fell out of settling the real hardware.
    Dev board is not the Espressif ESP32-C6-DevKitC-1:
    - It's a third-party ESP32-C6-WROOM-1 board with 2x15 headers, dual USB-C
    (one behind a CH343 bridge, one native ESP32-C6 USB/JTAG), BOOT and RST
    buttons, and an RGB LED on GPIO8. The J1/J3 labels were Espressif's and
    meant nothing here, so pin references are now Left/Right.
    - Recorded the full header map. The board brings out all 23 usable GPIOs, so
    the existing pin assignment needed no rework: GPIO6 is on the left header,
    and GPIO18-21 sit as a contiguous run at the bottom-right corner alo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
    [icom-2730a-fan-controller.yaml]
2026-09-25 Reconcile device name, add web UI, and fix tach RPM conversion
    Changes from first bring-up on real hardware.
    Repo/device reconciliation:
    - Rename icom-2730a-fan-controller.yaml -> icom2370a-fan-controller.yaml and
    set esphome.name to match. The repo and the flashed device had diverged
    (transposed digits, different hyphenation), so every firmware conclusion
    during debugging had to be caveated. Device Builder can now point at the
    repo file directly.
    - Add esphome.project (brulejr.radio-case-fan-controller 0.1.0) so the running
    build identifies itself in the boot log, mDNS and the API device_info.
    Local web UI:
    - web_server on port 80 with HTTP auth. local: true embeds the CSS/JS in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
    [icom2370a-fan-controller.yaml]
2026-09-26 Stop pinning the DS18B20 1-Wire address
    The config carried address: 0x0000000000000000, which ESPHome was already
    treating as unset — it auto-selects the sole device on the bus and logs the
    address it found. Removing the option makes that behaviour explicit rather
    than incidental.
    This also keeps the firmware portable. The README describes the module as
    "reusable for other go-box modules", and a pinned address would mean editing
    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
    [icom2370a-fan-controller.yaml]
2026-09-26 Treat U1 as a generic 12V to 5V buck converter
    No specific part is needed. Any module that takes 12 V in and presents 5 V on a
    USB-C output works, rated 1 A or better against a worst-case load of ~0.55 A.
    Drops the "part TBC" marker and the note chasing the original UMLIFE module,
    which was never going to match a fixed USB-C output anyway.
    The USB-C output stays in the BOM description because it isn't a part detail —
    it's what forces the whole power topology: 5 V reaches the carrier board
    through the dev board's USB-C port rather than arriving on a terminal.
2026-09-26 Document setpoint persistence, reset the TODO list, add board photo
    Gotcha: the three fan-curve setpoints persist in flash and outrank the YAML.
    They are restore_value: true, so initial_value applies only to a device that
    has never had one set. Once Min Temp, Max Temp or Minimum Duty is changed from
    the web UI or Home Assistant, that value survives reboots and OTA updates, and
    the config file stops being the source of truth. This caught us during
    bring-up — a test value of 19 C stayed live while the YAML still read 25 — so
    the note points at the [D][fan] log line as the way to read the live values.
    TODO list:
    - Close out "bench-test fan curve against actual enclosure thermal load". Both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
2026-09-26 Mark prototype as in production use, add a Problem solving section
    Status: the module is no longer a breadboard experiment. It runs in the radio
    case on a protoboard carrier with temperature-driven fan control, dual-fan
    operation and RPM monitoring all verified on hardware. Next milestone is the
    custom PCB, then the enclosure.
    Pulse counters return to update_interval: 60s. The 10s setting was a bring-up
    aid and the comment now frames it that way — drop to 10s temporarily if a tach
    problem arises, and put it back afterwards.
    New Problem solving section in the README, ahead of TODO, capturing what
    actually cost time during first bring-up:
    - Read the [D][fan] log line first. It carries the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
    [icom2370a-fan-controller.yaml]
2026-10-01 Swap fan pin assignments to match the physical wiring
    The outbound fan (Fan 1) is wired to GPIO20 (PWM) and GPIO21 (tach), the
    inbound fan (Fan 2) to GPIO18/GPIO19. The config had them the other way
    round, so the RPM entities were mislabelled and single-fan mode ran the
    inbound fan instead of the outbound one.
    [icom2370a-fan-controller.yaml]
2026-10-01 Add carrier PCB rev A (KiCad 8) and update docs
    A 90 x 54 mm two-layer carrier for the ESP32-C6 dev board, all through-hole
    passives, sized for a Hammond 1590B or a bare-board mount in the radio case.
    - On-board R-78E5.0-1.0 12V->5V regulator replaces the USB-C buck module
    - Dev board socketed on 2x15 headers; antenna end over a copper keepout
    - Keyed 4-pin fan headers, JST XH top-entry probe connector, 5.08 mm 12V
    screw terminal
    - Tach lines: 10k pull-up plus 1 nF to GND at the GPIO; PWM lines: 220R plus
    10 nF; 1-Wire series/shunt footprints left as spares; fan 5V decoupling
    - Mounting holes isolated from GND; chamfered traces
    - fit-template.pdf: 1:1 printable outline for space checkin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
    [fan-controller-carrier.kicad_pcb, fan-controller-carrier.kicad_sch]
2026-10-02 Mark header spacing confirmed and document fab outputs
    The dev board's header rows are confirmed at 25.4 mm, so the PCB is ready to
    order. The PCB README now gives the exact Gerber/drill export commands, the
    expected hole counts and outline for checking a fab's preview, and the order
    settings.
2026-10-02 Adds initial radio case installation photo
2026-10-02 Add KiCad's default schematic and ERC settings to the project file
    Written by KiCad when the schematic was opened in the editor. It adds the
    standard ERC rule severities and default schematic/BOM/plot settings; the
    board settings and design rules are unchanged, and ERC and DRC (with
    schematic parity) remain clean.
